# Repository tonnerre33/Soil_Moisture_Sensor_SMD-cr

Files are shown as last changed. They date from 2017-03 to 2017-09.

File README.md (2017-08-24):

# Soil Moisture Sensor SMD

# What is this ?

Simple office plant monitor inspired by [@carlierd](https://www.openhardware.io/user/97/projects/carlierd) on the [this](https://www.openhardware.io/view/123/Office-plant-monitor) post.

This is my first SMD project, i hope he'll used by other members ;)

The skech is 2.0.0 Mysensors compatible, i haven't test this sketch with the 2.1.1 version.

You can order the pcb here : https://PCBs.io/share/zjX7M

Soil Moisture Sensor SMD

The PCB files are for the V1.1.2 version, i haven't posted the V1.1 because there were important mistakes on the v1.1.

I have put 3 leds on this project :

* one connected on SCK for see the same thing than an arduino pro mini
* one for see when the node is initialised and when is goes in a sleep mode
* one not used for the moment, my idea was to use this led for offline node but i don't know how to do this without alterate the autonomie of the battery :(

# Features :

* Send Soil moisture mesure every hours
* Send Battery Level every hours if the value has changed
* Send Battery voltage every hours if the percentage has changed

# Compatibilies :

* Mysensors Library 2.0.0
* PCBs v1.1.x compatibles with Soil_Moisture_Sensor_SMD_v1.1.x sketchs

# Logs PCB :
## V1.1.2

* 16/02/2017 = Fabrication V1.1.2 by PCBs.io => Awaiting Panelization
* 20/02/2017 = Fabrication V1.1.2 by PCBs.io => In Fabrication
* 27/02/2017 = Fabrication V1.1.2 by PCBs.io => Shipped
* 09/03/2017 = Fabrication V1.1.2 by PCBs.io => Received
* 11/03/2017 = Assembly and Test => Functional Board but some minors issues => see v1.1.2a

## V1.1.2a
### minors modifications

* Increase Drill battery older CR123
* Modify text "FTDI" by "AVRISP"
* Add text "FTDI"

# Logs Sketch:
## V1.1.1

* Add default values
* Do not send moisture to the controler if she didn't change more than 1%
* Change Low Fuse example

## V1.1.2
* Fixed "Do not send moisture to the controler if she didn't change more than 1%"
* Added possibility to blink the "info" led when insufficient moisture
* Added possibility to blink the "warning" led when insufficient battery
* Added possibility to use this node without controler (need mysensors >= 2.1.0)
* Disable smartsleep when not OTA used (increase battery life)

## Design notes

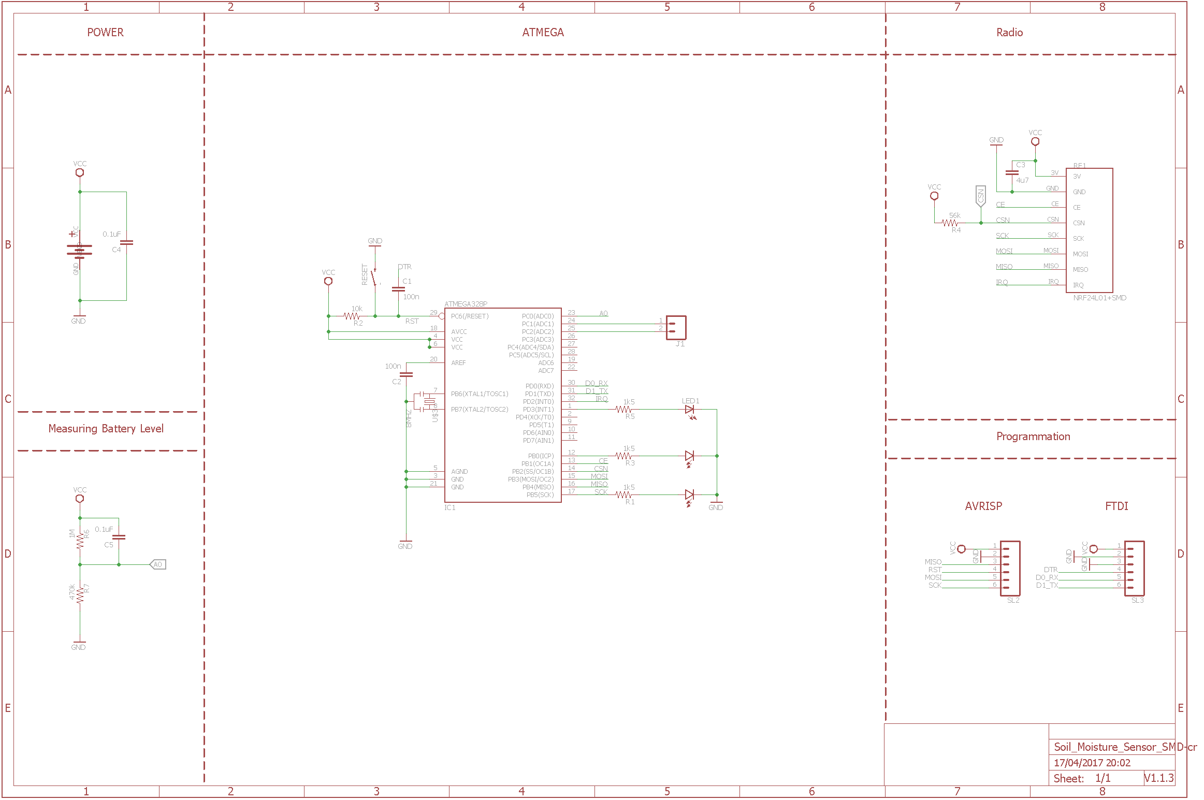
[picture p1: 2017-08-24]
Soil_Moisture_Sensor_SMD-cr.png

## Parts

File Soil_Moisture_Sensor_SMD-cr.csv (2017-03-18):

Qty | Value | Device | Package | Parts | Description
1 |  | CONN_02 | 1X02 | J1 | Multi connection point. Often used as Generic Header-pin footprint for 0.1 inch spaced/style header connections
1 |  | CR123-BATTERYHOLDER | CR123_BATTERYHOLDER | U$1 | CR123 Lithium Battery Holder
2 |  | LED0805 | 0805-LED | D1, D2
1 |  | LED3MM | LED3MM | LED1 | LED
1 |  | M06SIP | 1X06 | SL3 | Header 6
1 |  | M06SMD-1MM | 1X06-1MM | SL2 | Header 6
1 | - | SWITCH-MOMENTARY-2-SMD-1101NE | TACTILE-SWITCH-1101NE | RESET
2 | 0.1uF | CAP0805-CAP | 0805-CAP | C4, C5 | Capacitor
2 | 100n | CAP0805-CAP | 0805-CAP | C1, C2 | Capacitor
1 | 10k | RESISTOR0805-RES | 0805-RES | R2 | Resistor
1 | 1M | RESISTOR0805-RES | 0805-RES | R6 | Resistor
3 | 1k5 | RESISTOR0805-RES | 0805-RES | R1, R3, R5 | Resistor
1 | 470k | RESISTOR0805-RES | 0805-RES | R7 | Resistor
1 | 4u7 | CAP0805-CAP | 0805-CAP | C3 | Capacitor
1 | 56k | RESISTOR0805-RES | 0805-RES | R4 | Resistor
1 | 8MHZ | RESONATORSMD | RESONATOR-SMD | U$3 | Resonator
1 | ATMEGA328P | ATMEGA168/328TQFP32 | TQFP32-08 | IC1 | Atmel 32-pin 8-bit micro, 16k flash.
1 | NRF24L01+SMD | NRF24L01+SMD_MODULE | NRF24L01+SMD_MODULE | RF1

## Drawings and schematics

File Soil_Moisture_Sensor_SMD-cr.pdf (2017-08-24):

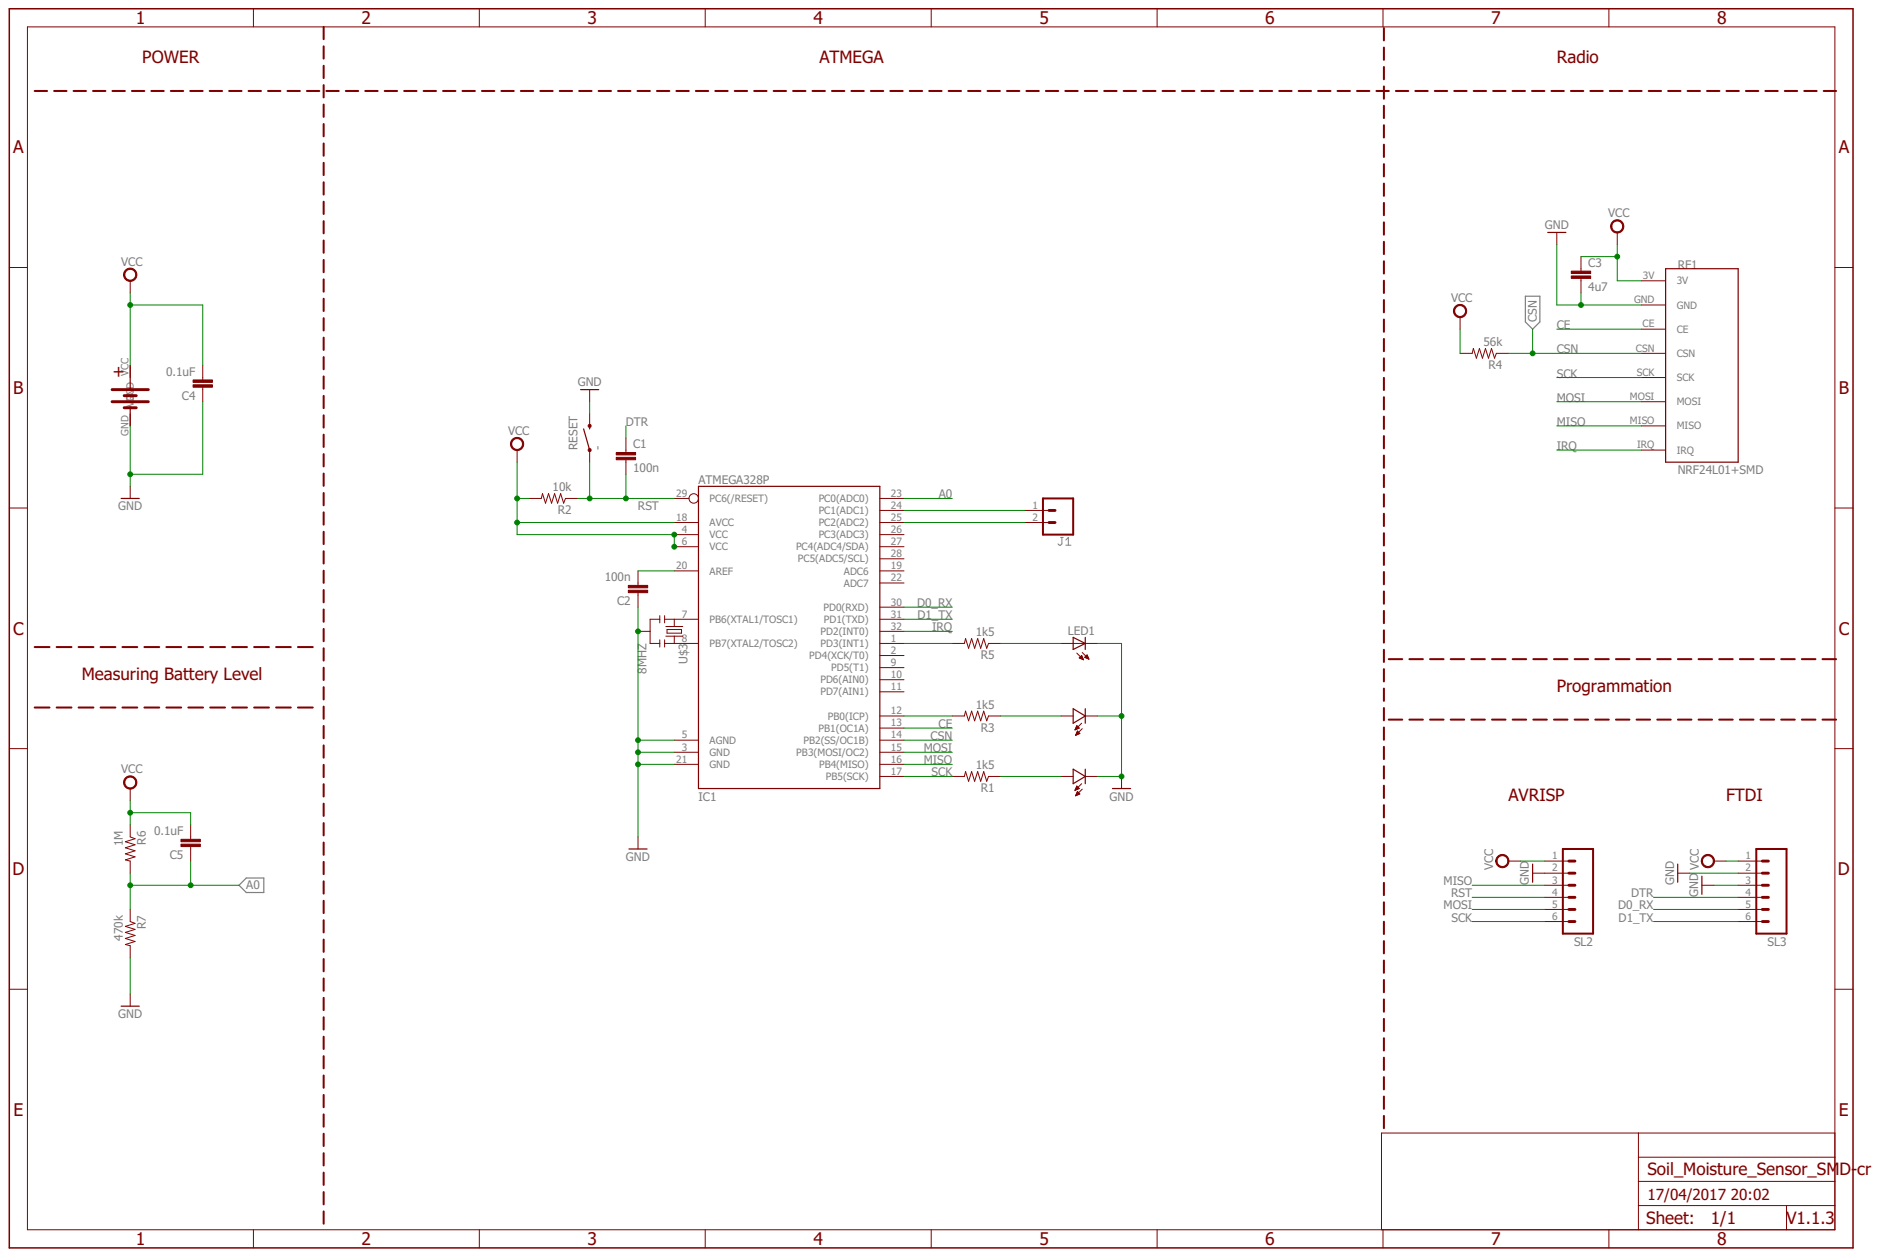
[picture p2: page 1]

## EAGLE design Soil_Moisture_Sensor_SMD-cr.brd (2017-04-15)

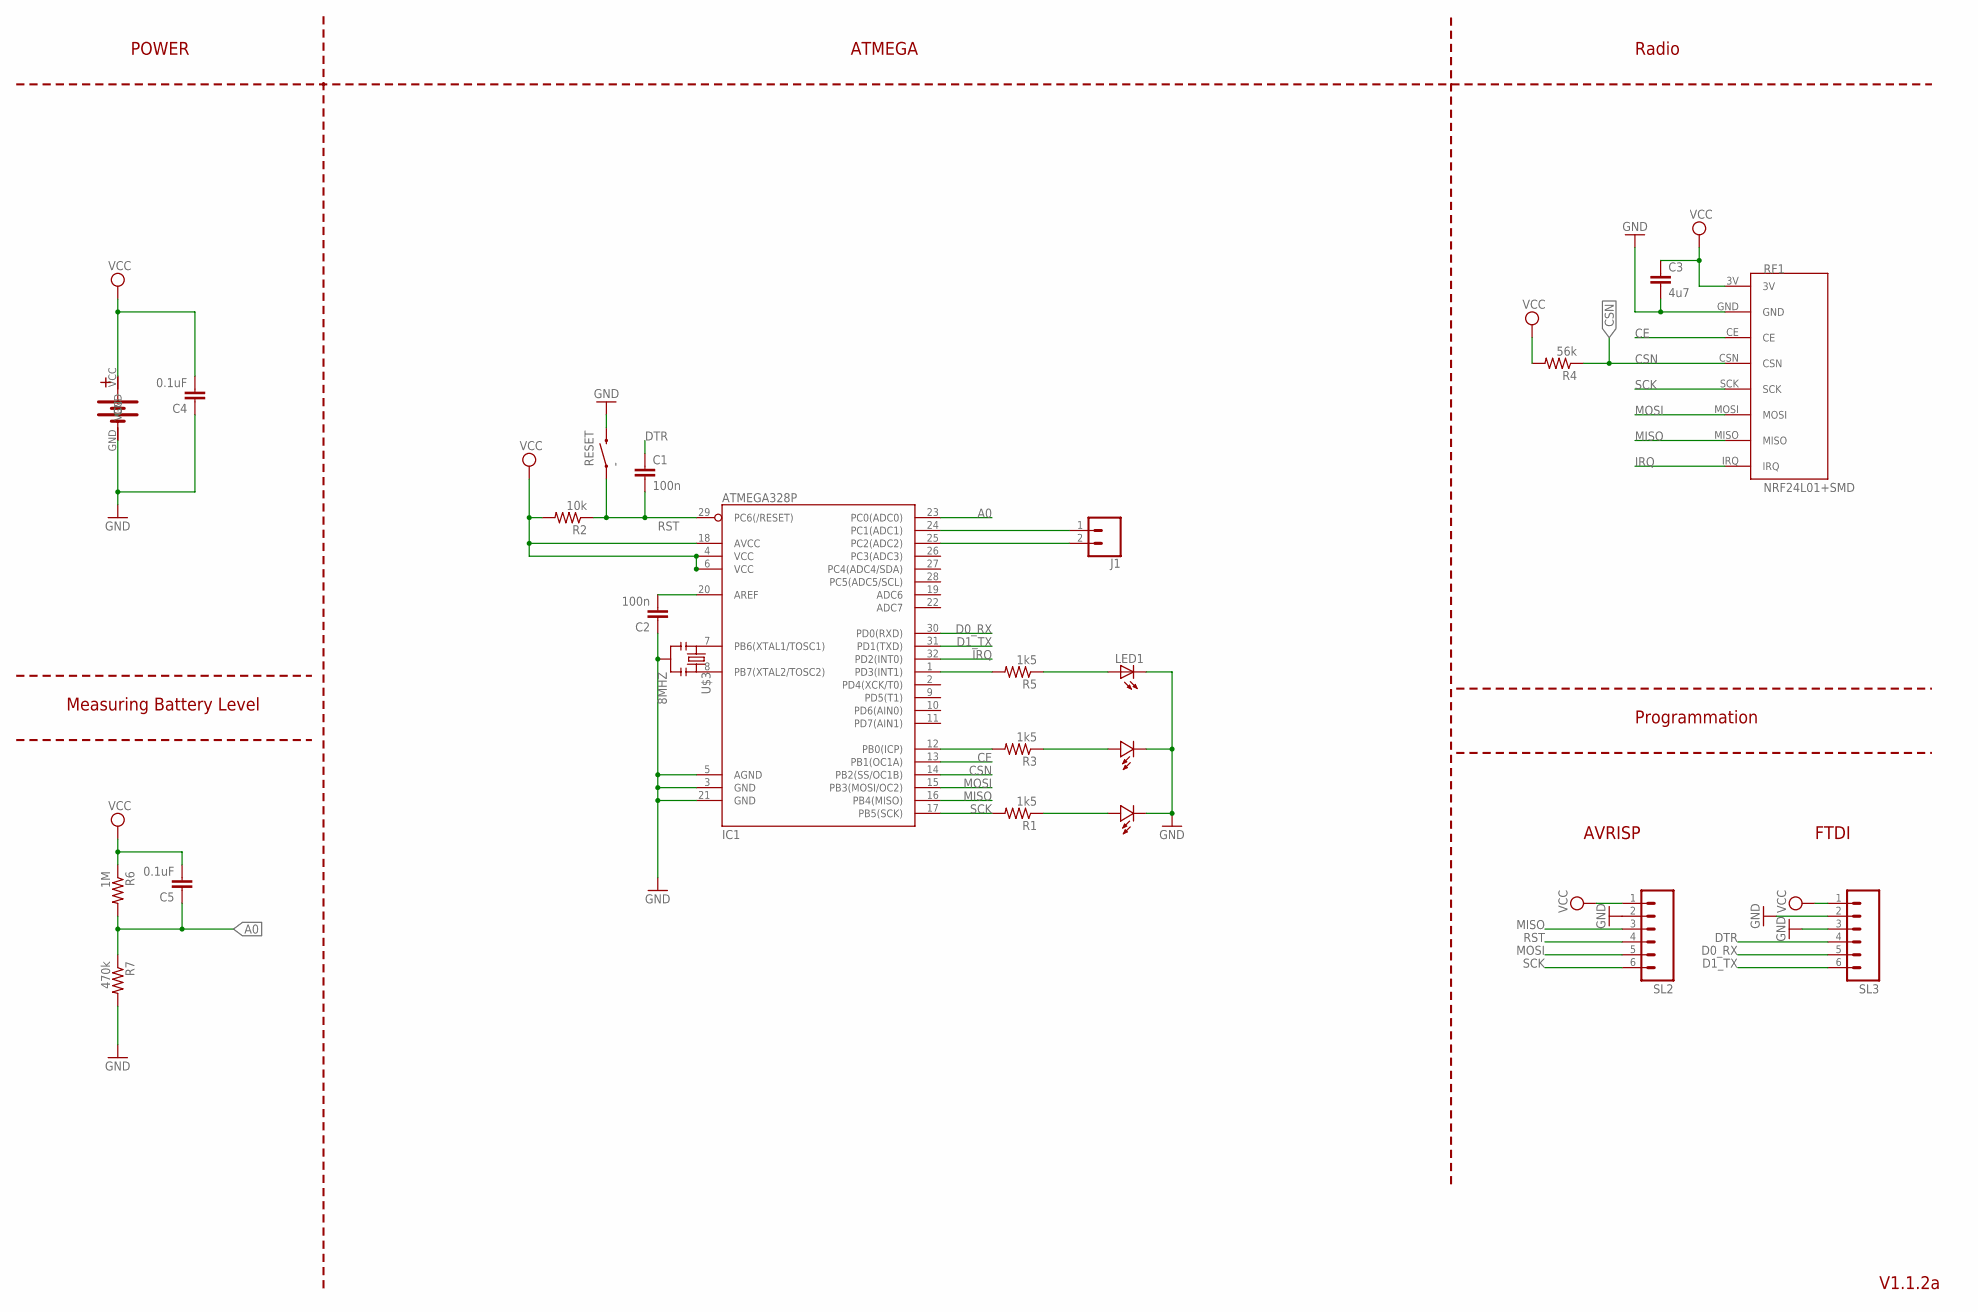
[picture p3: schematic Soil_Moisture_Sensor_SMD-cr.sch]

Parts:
C1, C2: 100n; 0805-CAP
C3: 4u7; 0805-CAP
C4, C5: 0.1uF; 0805-CAP
D1, D2: LED0805; 0805-LED
IC1: ATMEGA328P; TQFP32-08
J1: CONN_02; 1X02
LED1: LED5MM
R1, R3, R5: 1k5; 0805-RES
R2: 10k; 0805-RES
R4: 56k; 0805-RES
R6: 1M; 0805-RES
R7: 470k; 0805-RES
RESET: -; TACTILE-SWITCH-1101NE
RF1: NRF24L01+SMD; NRF24L01+SMD_MODULE
SL2, SL3: M06SMD-1MM; 1X06-1MM
U$1: CR123-BATTERYHOLDER; CR123_BATTERYHOLDER
U$3: 8MHZ; RESONATOR-SMD

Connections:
A0: C5.1, IC1.23 (PC0(ADC0)), R6.2, R7.1
CE: IC1.13 (PB1(OC1A)), RF1.CE
CSN: IC1.14 (PB2(SS/OC1B)), R4.1, RF1.CSN
D0_RX: IC1.30 (PD0(RXD)), SL3.5
D1_TX: IC1.31 (PD1(TXD)), SL3.6
DTR: C1.1, SL3.4
GND: C2.1, C3.2, C4.1, D1.MINUS, D2.MINUS, IC1.3 (GND), IC1.5 (AGND), IC1.21 (GND), LED1.K (C), R7.2, RESET.P$2 (2), RF1.GND, SL2.2, SL3.2, SL3.3, U$1.GND, U$3.2
IRQ: IC1.32 (PD2(INT0)), RF1.IRQ
MISO: IC1.16 (PB4(MISO)), RF1.MISO, SL2.3
MOSI: IC1.15 (PB3(MOSI/OC2)), RF1.MOSI, SL2.5
unnamed: D2.PLUS, R1.1
unnamed: IC1.7 (PB6(XTAL1/TOSC1)), U$3.1
unnamed: IC1.25 (PC2(ADC2)), J1.2
unnamed: C2.2, IC1.20 (AREF)
unnamed: IC1.24 (PC1(ADC1)), J1.1
unnamed: IC1.12 (PB0(ICP)), R3.2
unnamed: D1.PLUS, R3.1
unnamed: IC1.8 (PB7(XTAL2/TOSC2)), U$3.3
unnamed: IC1.1 (PD3(INT1)), R5.2
unnamed: LED1.A, R5.1
RST: C1.2, IC1.29 (PC6(/RESET)), R2.1, RESET.P$1 (1), SL2.4
SCK: IC1.17 (PB5(SCK)), R1.2, RF1.SCK, SL2.6
VCC: C3.1, C4.2, C5.2, IC1.4 (VCC), IC1.6 (VCC), IC1.18 (AVCC), R2.2, R4.2, R6.1, RF1.3V, SL2.1, SL3.1, U$1.VCC

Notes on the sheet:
Programmation
FTDI
AVRISP
Radio
ATMEGA
POWER
Measuring Battery Level
V1.1.2a

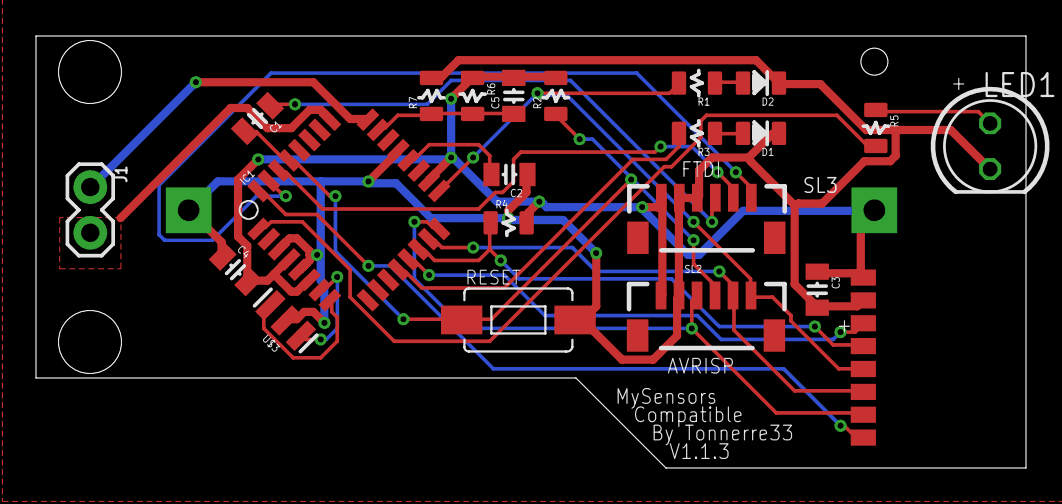
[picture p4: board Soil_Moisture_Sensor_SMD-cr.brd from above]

Board: 2 copper layers, 55.0 x 24.0 mm, 23 parts (1 on the bottom side), 23 nets.

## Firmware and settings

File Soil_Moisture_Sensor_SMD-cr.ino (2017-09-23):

/**
* The MySensors Arduino library handles the wireless radio link and protocol
* between your home built sensors/actuators and HA controller of choice.
* The sensors forms a self healing radio network with optional repeaters. Each
* repeater and gateway builds a routing tables in EEPROM which keeps track of the
* network topology allowing messages to be routed to nodes.
*
* Created by Henrik Ekblad <henrik.ekblad@mysensors.org>
* Copyright (C) 2013-2015 Sensnology AB
* Full contributor list: https://github.com/mysensors/Arduino/graphs/contributors
*
* Documentation: http://www.mysensors.org
* Support Forum: http://forum.mysensors.org
*
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
* Code and ideas from
* mfalkvidd (http://forum.mysensors.org/user/mfalkvidd),
* carlierd (https://www.openhardware.io/user/97/projects/carlierd)
* Scalz (https://www.openhardware.io/user/12/projects/scalz)
*/

/**************************************************************************************/
/* Moisture sensor SMD.                                                               */
/*                                                                                    */
/* Version     : V1.1.3                                                               */
/* Supported Hardware     : V1.1.x                                                    */
/* Date        : 23/09/2017                                                           */
/* Modified by : Jordan Bouey                                                         */
/**************************************************************************************/

/* Fuse L:E2 H:DA E:06 x
*  BOD 1.8V - Int 8Mhz Osc
*  avec boot  ATmegaBOOT_168_atmega328_pro_8MHz.hex
*/

//#define NODE_WITHOUT_GATEWAY //uncomment if you don't use a gateway

//#define MY_NODE_ID 12
//#define MY_DEBUG    // Enables debug messages in the serial log

#ifdef NODE_WITHOUT_GATEWAY
//if you want to use this node without controler set MOISTURE_WARN_PCNT != 0
#define MY_TRANSPORT_WAIT_READY_MS 10 //Set for use this node in standalone mode = no need a controler for run (need library mysensors >= 2.1.0)
#define MY_SLEEP_TRANSPORT_RECONNECT_TIMEOUT_MS 0
#endif

// Enable and select radio type attached
#define MY_RADIO_NRF24
//#defin MY_OTA //Enables smart sleep if you use OTA
//#define MY_OTA_FIRMWARE_FEATURE  // Enables OTA firmware updates if DualOptiBoot
// Enables software signing
//#define MY_SIGNING_SOFT
// SETTINGS FOR MY_SIGNING_SOFT
//#define MY_SIGNING_SOFT_RANDOMSEED_PIN 7  //!< Unconnected analog pin for random seed
// Enable node whitelisting
//#define MY_SIGNING_NODE_WHITELISTING {{.nodeId = 0,.serial = {0xEB,0x86,0x43,0x73,0x14,0xB1,0xAF,0x0E,0x17}}}
// Enable this if you want destination node to sign all messages sent to this node.
// If enabled, You need to use securityPersonalizer for more security and change the default HMAC_KEY (https://www.mysensors.org/about/signing)
//#define MY_SIGNING_REQUEST_SIGNATURES



#include <MySensors.h>
#include <SPI.h>

//Define functions
#define round(x) ((x)>=0?(long)((x)+0.5):(long)((x)-0.5))
#define N_ELEMENTS(array) (sizeof(array)/sizeof((array)[0]))

//Constants for MySensors
#define SKETCH_NAME           "Moisture Sensor SMD"
#define SKETCH_VERSION        "1.1.3"

//User Constants
#define MOISTURE_WARN_PCNT    0 //MOISTURE WARNING PERCENT (default 0) 0 = disabled
#define BATTERY_WARN_PCNT     10 //BATTERY_WARN_PCNT WARNING PERCENT (default 10) 0 = disabled

//Internal Constants
#define CHILD_ID_VOLTAGE      0 // Id of the sensor child (default 0)
#define CHILD_ID_MOISTURE     1   // Id of the sensor child (default 1)
#define BATTERY_SENSE_PIN     A0  // select the input pin for the battery sense point (default A0)
#define LED_PIN_INFO          8 //INFO LED PIN (default 8)
#define LED_PIN_WARN          3 //WARNING LED PIN (default 3)
#define THRESHOLD             1.1     // Only make a new reading with reverse polarity if the change is larger than 10% (default 1.1)
#define MOISTURE_THRESHOLD    1    // Delta needing for sending moisture to the controler in percent (default 1)
#define STABILIZATION_TIME    2000    // Let the sensor stabilize before reading (default 2000)
#define BATTERY_FULL          3240    // when full CR123A (default 3240)
#define BATTERY_ZERO          2340    // 2.34V limit for 328p at 8MHz (set extended fuse to 0x06 for BOD 1.8V or you'll never see 2.34V)  (default 2340)
const int SENSOR_ANALOG_PINS[] = {A1, A2}; //(default {A1, A2})

#ifdef MY_DEBUG
#define MEASURE_INTERVAL      10000 // Minimal Measure interval even if sleep time is smaller (default 10000)(10 sec)
#define WARN_TIME             5000 //WARNING REPEAT TIME (in milliseconds) (default 5000)(5sec)
#else
#define MEASURE_INTERVAL      3600000 // Minimal Measure interval even if sleep time is smaller (default 3600000)(1 hour)
#define WARN_TIME             45000 //WARNING REPEAT TIME (in milliseconds) (default 45000)(45sec)
#endif



//Variables
int oldbatteryPcnt = -1;
byte direction = 0;
int oldMoistureLevel = -1;
int oldMoisturePcnt = -1;
int moisturePcnt = -1;
int batteryPcnt = -1;
long sleepTime = MEASURE_INTERVAL;
long lastMeasure = MEASURE_INTERVAL;

MyMessage msgVolt(CHILD_ID_VOLTAGE, V_VOLTAGE);
MyMessage msgMoisture(CHILD_ID_MOISTURE, V_HUM);


/**************************************************************************************/
/* Presentation                                                                       */
/**************************************************************************************/
void presentation()
{
  //Get time (for presentation)
  #ifdef MY_DEBUG
  unsigned long startTime = millis();
  #endif
  
  #ifndef NODE_WITHOUT_GATEWAY
  //Start MySensors and send the sketch version information to the gateway
  sendSketchInfo(SKETCH_NAME, SKETCH_VERSION);
  
  //Register all sensors
  present(CHILD_ID_VOLTAGE, S_MULTIMETER);
  present(CHILD_ID_MOISTURE, S_MOISTURE);
  #endif
  
  //Setup LED INFO pin
  pinMode(LED_PIN_INFO, OUTPUT);
  
  //Setup done !
  blinkLedFastly(3, LED_PIN_INFO);
  
  //Print setup debug
  #ifdef MY_DEBUG
  int duration = millis() - startTime;
  Serial.print("[Presentation duration: "); Serial.print(duration, DEC); Serial.println(" ms]");
  #endif
  }
/**************************************************************************************/
/* Initialization                                                                     */
/**************************************************************************************/
void setup()
{
  
  //Setup LED WARNING pin
  pinMode(LED_PIN_WARN, OUTPUT);
  
  //Set moisutre sensor pins
  for (int i = 0; i < N_ELEMENTS(SENSOR_ANALOG_PINS); i++)
  {
    pinMode(SENSOR_ANALOG_PINS[i], OUTPUT);
    digitalWrite(SENSOR_ANALOG_PINS[i], LOW);
    }
  
  }

/**************************************************************************************/
/* Main loop                                                                          */
/**************************************************************************************/
void loop()
{
  //Get time (for a complete loop)
  #ifdef MY_DEBUG
  unsigned long startTime = millis();
  #endif
  
  #ifdef MY_DEBUG
  Serial.print("lastMeasure: ");
  Serial.println(lastMeasure);
  #endif
  
  if(lastMeasure >= MEASURE_INTERVAL) {
    
    
    //Get moisture level
    int moistureLevel = readMoisture();
    
    //Send rolling average of 2 samples to get rid of the "ripple" produced by different resistance in the internal pull-up resistors
    //See http://forum.mysensors.org/topic/2147/office-plant-monitoring/55 for more information
    
    //Verify if current measurement is not too far from the previous one
    if (moistureLevel > (oldMoistureLevel * THRESHOLD) || moistureLevel < (oldMoistureLevel / THRESHOLD))
    {
      //The change was large, so it was probably not caused by the difference in internal pull-ups.
      //Measure again, this time with reversed polarity.
      moistureLevel = readMoisture();
      }
    
    
    #ifdef MY_DEBUG
    Serial.print("Soil Value: ");
    Serial.println(moistureLevel);
    #endif
    
    if (oldMoistureLevel == -1) {
      oldMoistureLevel = moistureLevel;
      }
    
    // int moisturePcnt = (moistureLevel + oldMoistureLevel) / 2.0 / 10.23;
    moisturePcnt = moistureLevel / 10.23;
    if (moistureLevel >= (oldMoistureLevel +  10.23 * MOISTURE_THRESHOLD) || moistureLevel <= (oldMoistureLevel - 10.23 * MOISTURE_THRESHOLD) || oldMoisturePcnt == -1) //Send moisture only if moisture changed more than MOISTURE_THRESHOLD (control change value percent and not a cast)
    {
      if (moisturePcnt >= (oldMoisturePcnt +  MOISTURE_THRESHOLD) || moisturePcnt <= (oldMoisturePcnt - MOISTURE_THRESHOLD) || oldMoisturePcnt == -1) //Send moisture only if moisture percent changed more than MOISTURE_THRESHOLD (control if display changed)
      {
        #ifndef NODE_WITHOUT_GATEWAY
        send(msgMoisture.set(moisturePcnt));
        #endif
        //Store current moisture pcnt
        oldMoisturePcnt = moisturePcnt;
        //Store current moisture level
        oldMoistureLevel = moistureLevel;
        
        }
      }
    }
  
  
  
  if(lastMeasure >= MEASURE_INTERVAL) {
    //Report data to the gateway
    long voltage = getVoltageByHard();
    batteryPcnt = round((voltage - BATTERY_ZERO) * 100.0 / (BATTERY_FULL - BATTERY_ZERO));
    
    if (batteryPcnt > 100) {batteryPcnt = 100;}
    if (batteryPcnt <= 0) {batteryPcnt = 0;}
    if (oldbatteryPcnt != batteryPcnt) {
      #ifndef NODE_WITHOUT_GATEWAY
      send(msgVolt.set(voltage / 1000.0, 2));
      sendBatteryLevel(batteryPcnt);
      #endif
      oldbatteryPcnt = batteryPcnt;
      
      }
    }
  
  if(lastMeasure >= MEASURE_INTERVAL) {
    lastMeasure = 0;
    }else{
    lastMeasure = lastMeasure + sleepTime;
    }
  
  //Calcul next sleep time
  if(batteryPcnt < BATTERY_WARN_PCNT || moisturePcnt < MOISTURE_WARN_PCNT)
  {
    if(WARN_TIME < MEASURE_INTERVAL){
      if(lastMeasure >= MEASURE_INTERVAL){ // if next loop = measure
        #ifdef MY_DEBUG
        blinkLedFastly(1, LED_PIN_INFO);
        #endif
        sleepTime = WARN_TIME - STABILIZATION_TIME;
        }else{
        #ifdef MY_DEBUG
        blinkLedFastly(2, LED_PIN_INFO);
        #endif
        sleepTime = WARN_TIME;
        }
      }
    
    //LED WARNING MOISTURE
    if(moisturePcnt < MOISTURE_WARN_PCNT) {blinkLedFastly(1, LED_PIN_WARN);}
    //LED WARNING BATTERY
    if(batteryPcnt < BATTERY_WARN_PCNT){blinkLedFastly(3, LED_PIN_WARN);}
    }
  else{
    blinkLedFastly(3, LED_PIN_INFO);
    sleepTime = MEASURE_INTERVAL;
    }
  
  
  
  
  
  
  //Print debug
  #ifdef MY_DEBUG
  Serial.print(moisturePcnt);
  Serial.print("%");
  Serial.print("   ");
  Serial.print(batteryPcnt);
  Serial.print("%");
  int duration = millis() - startTime;
  Serial.print("   ");
  Serial.print("["); Serial.print(duration, DEC); Serial.println(" ms]");
  Serial.flush();
  #endif
  
  //Sleep until next measurement - smart sleep for OTA
  #ifdef MY_OTA
  smartSleep(sleepTime);
  #else
  sleep(sleepTime);
  #endif
  }


/**************************************************************************************/
/* Allows to get moisture.                                                            */
/**************************************************************************************/
int readMoisture()
{
  //Power on the sensor and read once to let the ADC capacitor start charging
  pinMode(SENSOR_ANALOG_PINS[direction], INPUT_PULLUP);
  analogRead(SENSOR_ANALOG_PINS[direction]);
  
  //Stabilize and read the value
  sleep(STABILIZATION_TIME);
  int moistureLevel = (1023 - analogRead(SENSOR_ANALOG_PINS[direction]));
  
  //Turn off the sensor to conserve battery and minimize corrosion
  pinMode(SENSOR_ANALOG_PINS[direction], OUTPUT);
  digitalWrite(SENSOR_ANALOG_PINS[direction], LOW);
  
  //Make direction alternate between 0 and 1 to reverse polarity which reduces corrosion
  direction = (direction + 1) % 2;
  return moistureLevel;
  }

/**************************************************************************************/
/* Allows to fastly blink the LED.                                                    */
/**************************************************************************************/
void blinkLedFastly(byte loop, byte pinToBlink)
{
  byte delayOn = 150;
  byte delayOff = 150;
  for (int i = 0; i < loop; i++)
  {
    blinkLed(pinToBlink, delayOn);
    delay(delayOff);
    }
  }


/**************************************************************************************/
/* Allows to blink a LED.                                                             */
/**************************************************************************************/
void blinkLed(byte pinToBlink, int delayInMs)
{
  digitalWrite(pinToBlink,HIGH);
  delay(delayInMs);
  digitalWrite(pinToBlink,LOW);
  }

/**************************************************************************************/
/* Allows to get the real Vcc (return value in mV).                                   */
/* http://provideyourown.com/2012/secret-arduino-voltmeter-measure-battery-voltage/   */
/**************************************************************************************/
long getVoltageBySoft()
{
  ADMUX = (0<<REFS1) | (1<<REFS0) | (0<<ADLAR) | (1<<MUX3) | (1<<MUX2) | (1<<MUX1) | (0<<MUX0);
  delay(50);  // Let mux settle a little to get a more stable A/D conversion
  //Start a conversion
  ADCSRA |= _BV( ADSC );
  //Wait for it to complete
  while (bit_is_set(ADCSRA, ADSC));
  
  //Compute and return the value
  uint8_t low  = ADCL;                  // must read ADCL first - it then locks ADCH
  uint8_t high = ADCH;                  // unlocks both
  long result = (high << 8) | low;
  result = 1125300L / result;           // Calculate Vcc (in mV); 1125300 = 1.1*1023*1000
  return result;                        // Vcc in millivolts
  }


/**************************************************************************************/
/* Mesure battery with divider                                                        */
/*                                                                                    */
/**************************************************************************************/
long getVoltageByHard()
{
  analogReference(INTERNAL);
  
  // get the battery Voltage
  int sensorValue = analogRead(BATTERY_SENSE_PIN);
  #ifdef MY_DEBUG
  Serial.print("Battery Value: ");
  Serial.println(sensorValue);
  #endif
  
  //L'analog reférence ne change que lorsque l'on fait un analogread et il met un peu de temps à changer, d'où la tempo et la répétition de la commande analogRead
  delay(1000);     // this delay is needed
  sensorValue = analogRead(BATTERY_SENSE_PIN);
  
  
  #ifdef MY_DEBUG
  Serial.print("Battery Value: ");
  Serial.println(sensorValue);
  #endif
  
  // 1M, 470K divider across battery and using internal ADC ref of 1.1V
  // Sense point is bypassed with 0.1 uF cap to reduce noise at that point
  // ((1e6+470e3)/470e3)*1.1 = Vmax = 3.44 Volts
  // 3.44/1023 = Volts per bit = 0.003363075
  
  float batteryV  = sensorValue * 0.003363075;
  int batteryMv  = round(batteryV * 1000);
  // int batteryPcnt = sensorValue * 0.0977517106549365;
  
  int batteryPcnt = round((batteryMv - BATTERY_ZERO) * 100.0 / (BATTERY_FULL - BATTERY_ZERO));
  if (batteryPcnt > 100) {batteryPcnt = 100;}
  
  #ifdef MY_DEBUG
  
  Serial.print("Battery Voltage: ");
  Serial.print(batteryMv);
  Serial.println(" mV");
  
  Serial.print("Battery percent: ");
  Serial.print(batteryPcnt);
  Serial.println(" %");
  #endif
  
  analogReference(DEFAULT);
  return batteryMv;                        // Vcc in mV
  }

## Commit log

2017-03-19 fw-1.1.2 Move LED PIN info in presentation for compatibility with mysensors >2.1.0
2017-09-23 correct mode without gateway & auto indent code
    [Soil_Moisture_Sensor_SMD-cr.ino]

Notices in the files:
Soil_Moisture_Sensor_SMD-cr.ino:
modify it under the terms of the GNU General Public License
